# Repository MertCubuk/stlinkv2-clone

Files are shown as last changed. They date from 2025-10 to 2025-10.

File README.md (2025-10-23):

# ST-Link V2 Clone (Rev.2) — KiCad PCB Design

STM32 tabanlı bir ST-Link V2 programlayıcı kart tasarımıdır.  
Projede amaç, USB–SWD arayüzünü stabilize edecek şekilde hat eşitlemesi yapılmış,  
üretime uygun iki katmanlı bir PCB ortaya çıkarmaktır.

---

## Teknik Özellikler

- Mikrodenetleyici: STM32F103C8T6  
- Bağlantı: USB FS (12 Mbps), D+ / D− diferansiyel hat eş uzunluklu  
- Besleme: 5V → 3.3V LDO regülatör  
- Koruma: TVS diyot ile ESD koruması
- Arabirim: SWD, UART pin header (JTAG alternatifi)  
- Katman sayısı: 2  
- Minimum iz kalınlığı: 0.25 mm  
- Minimum via boyutu: 0.3 / 0.6 mm  
- PCB boyutu: Yaklaşık 70.75 × 30 mm  
- DRC: Hatasız (clearance & unconnected 0)

---

## Tasarım Notları

- D+ / D− hatları eş uzunlukta ve paralel olarak route edildi.  
- 3.3V ve 5V güç yolları kalınlaştırılarak düşük dirençli hat elde edildi.  
- Decoupling kondansatörleri MCU’ya fiziksel olarak en yakın konumda yerleştirildi.  
- Kristal çevresi kısa loop ve GND guard ile izole edildi.  
- GND plane sürekliliği korunarak düşük EMI hedeflendi.  
- Bileşenlerin silkscreen konumları okunabilirlik ve üretim kolaylığına göre düzenlendi.

---

## Görseller

### PCB Üst Katman (3D)
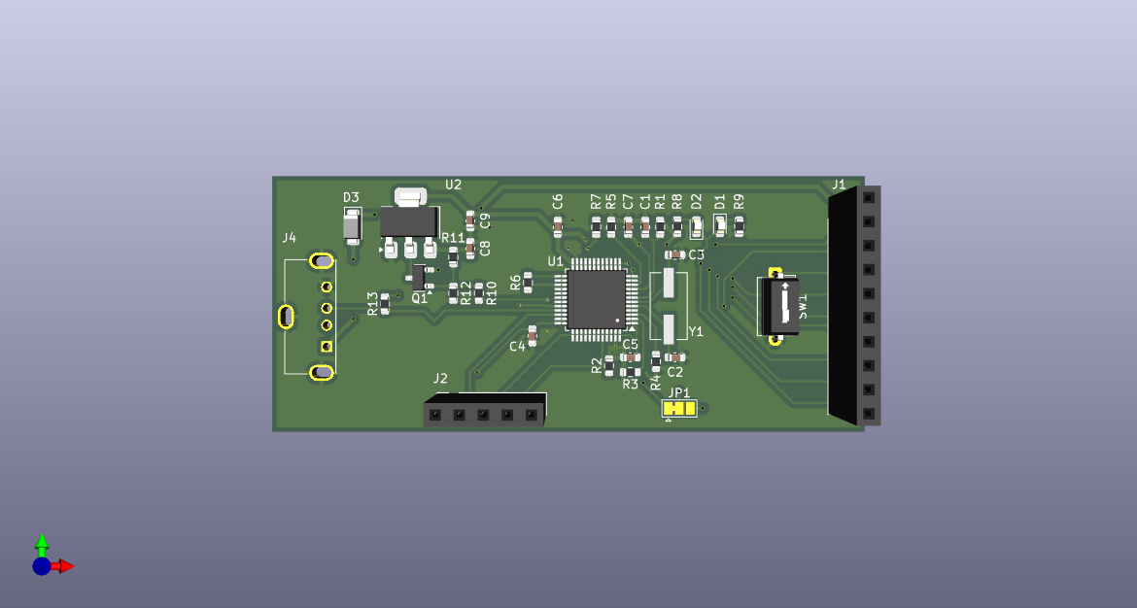
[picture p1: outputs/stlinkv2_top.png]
PCB Top


### PCB Alt Katman (3D)
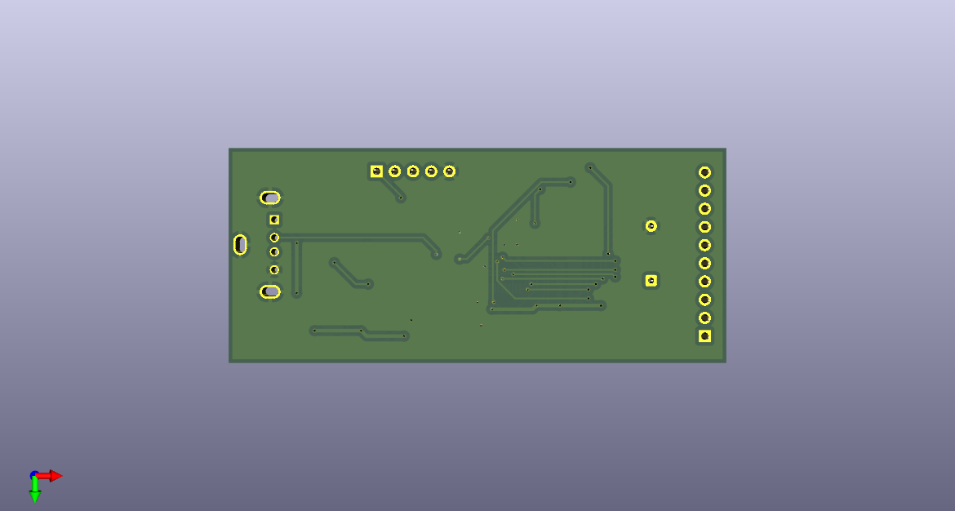
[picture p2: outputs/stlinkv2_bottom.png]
PCB Bottom


### Düzenleme Görünümü (KiCad)
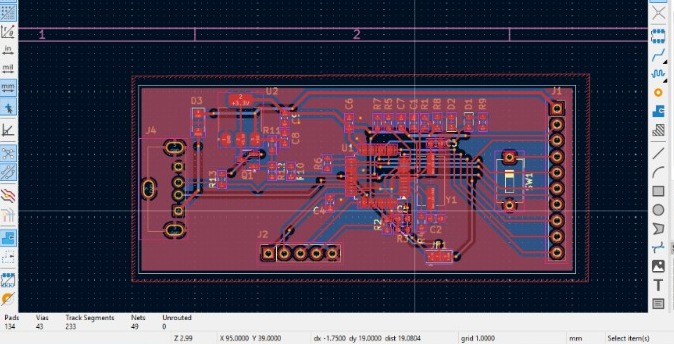
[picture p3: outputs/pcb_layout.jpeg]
PCB Layout


---

## Üretim ve Çıktılar

- Gerber + Drill dosyaları `outputs/gerbers_drill.rar` klasöründe yer alır.  
- JLCPCB / PCBWay üretim kurallarına uyumludur.  
- Şematik dosyası `.pdf` formatında eklendi (`stlinkv2_schmatic.pdf`).  
- BOM listesi ve netlist, KiCad v9+ üzerinde otomatik oluşturulabilir.

---

## Tasarım

Mert Çubuk  
Elektrik-Elektronik Mühendisi | Embedded Systems & PCB Design  
Ekim 2025  
LinkedIn: [https://www.linkedin.com/in/mert-%C3%A7ubuk-06b53536a/]

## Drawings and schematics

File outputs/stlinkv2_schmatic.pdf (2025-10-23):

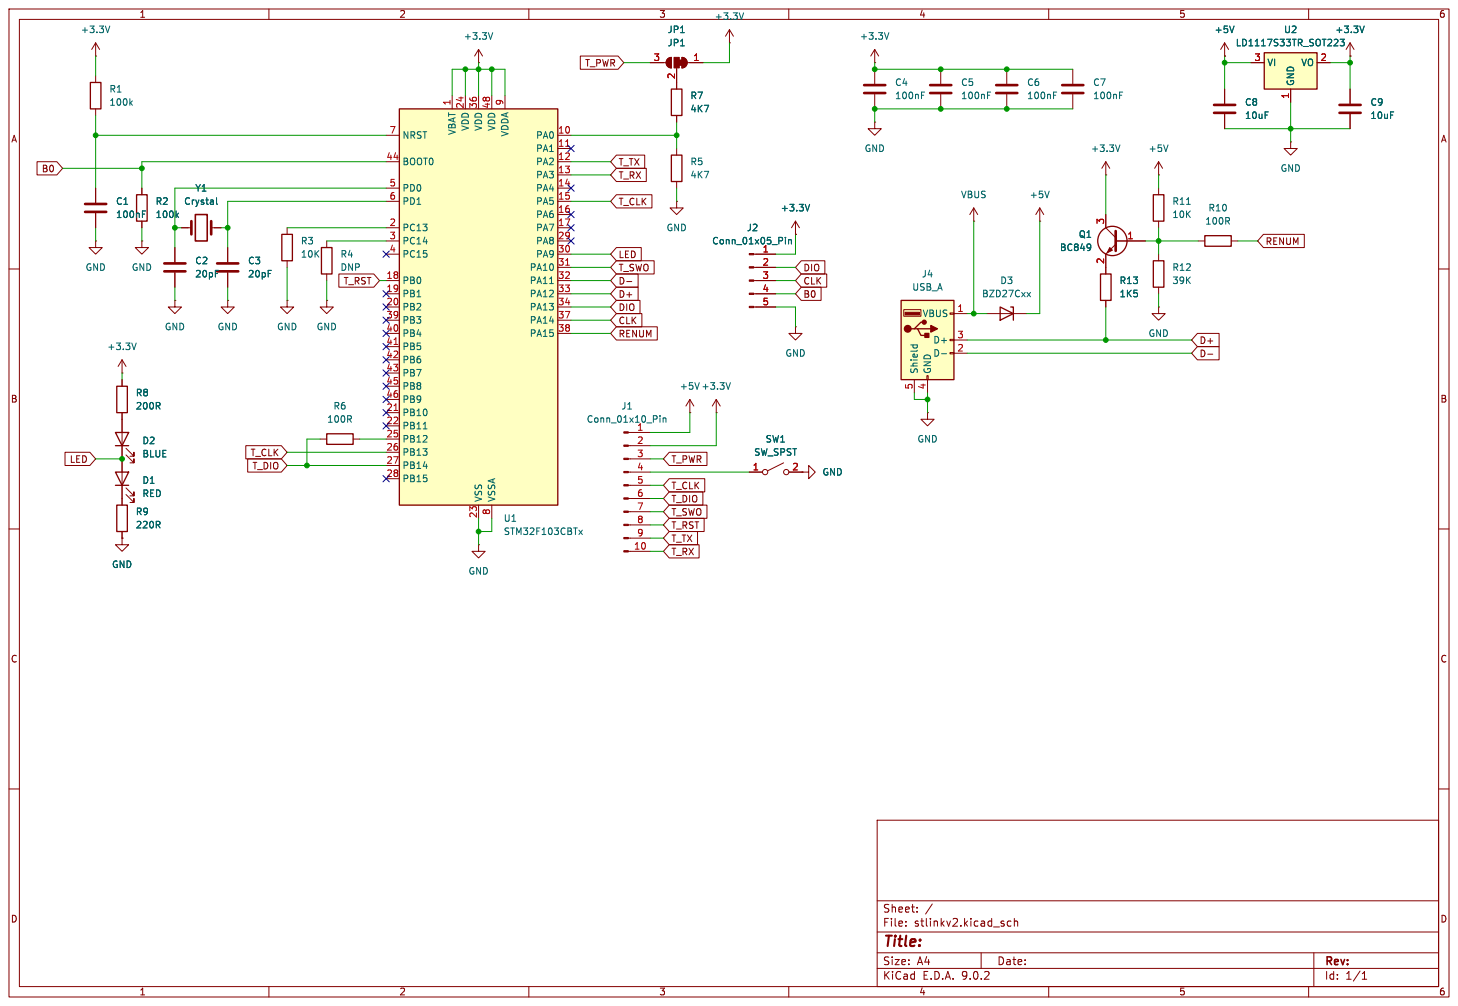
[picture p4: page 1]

1 VDD 24 VDD 36 VSS 23 VDD 48 VSSA

Id: 1/1 Title: File: stlinkv2.kicad_sch Sheet: /

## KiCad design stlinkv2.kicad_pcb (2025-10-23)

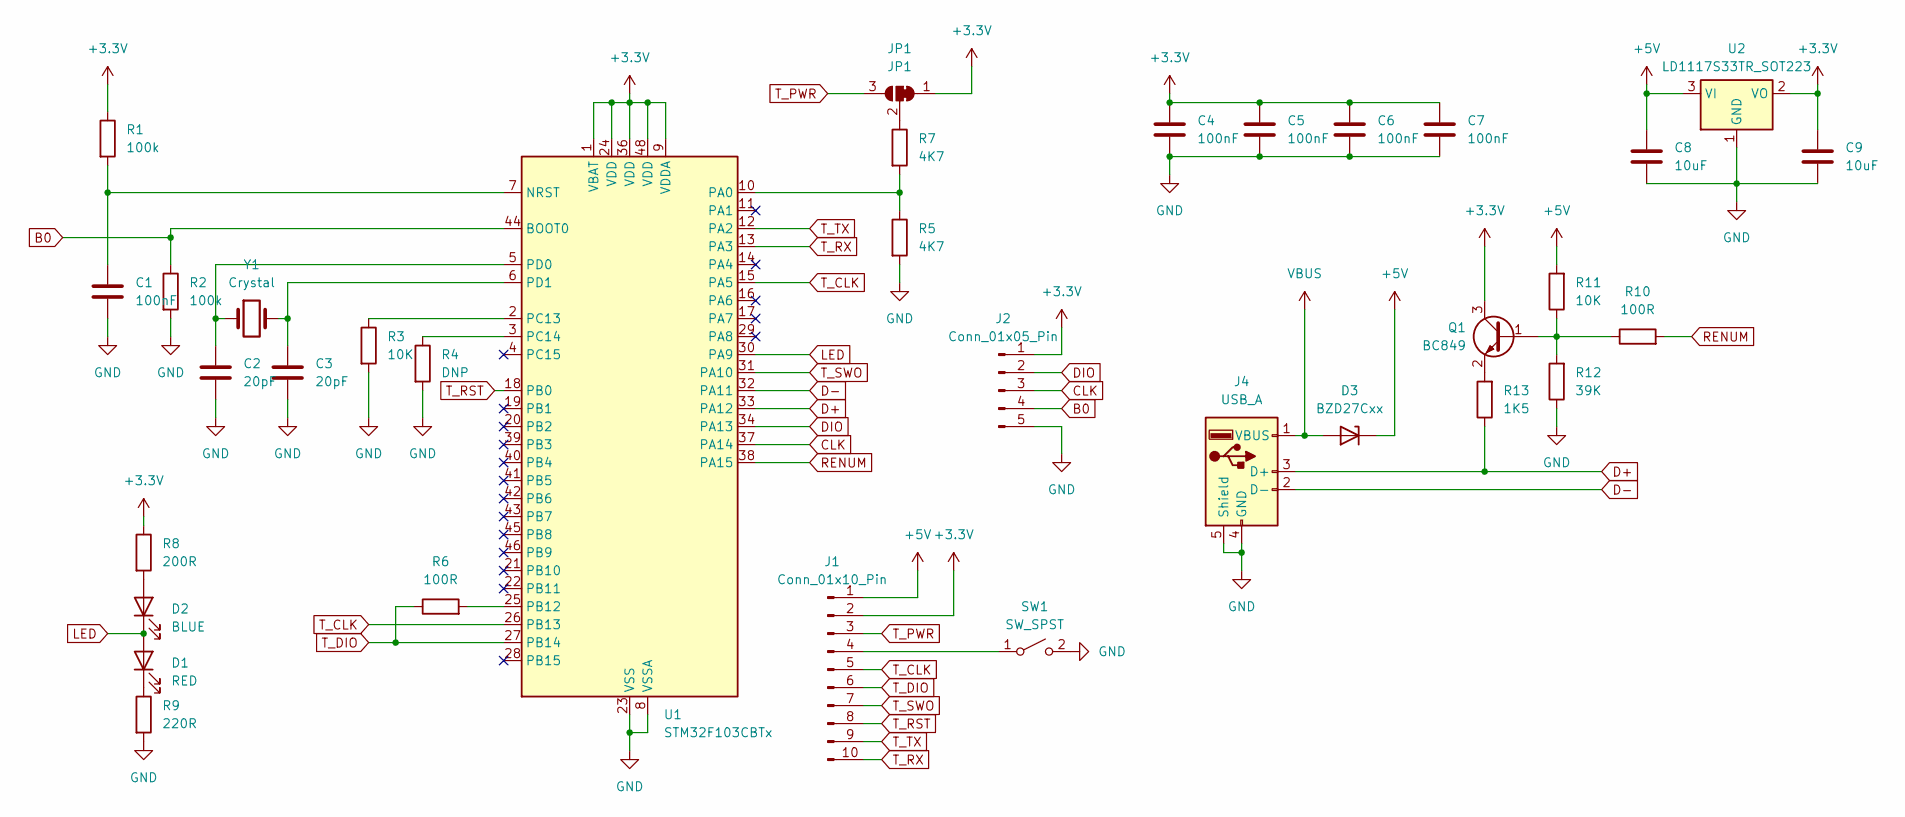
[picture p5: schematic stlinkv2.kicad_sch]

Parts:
C1, C4, C5, C6, C7: 100nF; C_0603_1608Metric
C2, C3: 20pF; C_0603_1608Metric
C8, C9: 10uF; C_0603_1608Metric
D1: RED; LED_0603_1608Metric
D2: BLUE; LED_0603_1608Metric
D3: BZD27Cxx; D_SMF
J1: Conn_01x10_Pin; PinSocket_1x10_P2.54mm_Vertical
J2: Conn_01x05_Pin; PinSocket_1x05_P2.54mm_Vertical
J4: USB_A; USB_A_Molex_105057_Vertical
JP1: JP1; SolderJumper-3_P1.3mm_Bridged12_Pad1.0x1.5mm
Q1: BC849; SOT-23
R1, R2: 100k; R_0603_1608Metric
R3, R11: 10K; R_0603_1608Metric
R4: DNP; R_0603_1608Metric
R5, R7: 4K7; R_0603_1608Metric
R6, R10: 100R; R_0603_1608Metric
R8: 200R; R_0603_1608Metric
R9: 220R; R_0603_1608Metric
R12: 39K; R_0603_1608Metric
R13: 1K5; R_0603_1608Metric
SW1: SW_SPST; SW_DIP_SPSTx01_Slide_6.7x4.1mm_W7.62mm_P2.54mm_LowProfile
U1: STM32F103CBTx; LQFP-48_7x7mm_P0.5mm
U2: LD1117S33TR_SOT223; SOT-223-3_TabPin2
Y1: Crystal; Crystal_SMD_ECS_CSM3X-2Pin_7.6x4.1mm

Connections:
+3.3V: C4.2, C5.2, C6.2, C7.2, C9.2, J1.2, J2.1, JP1.1 (A), Q1.3 (C), R1.1, R8.1, U1.1 (VBAT), U1.9 (VDDA), U1.24 (VDD), U1.36 (VDD), U1.48 (VDD), U2.2 (VO)
+5V: C8.2, D3.1 (K), J1.1, R11.2, U2.3 (VI)
B0: J2.4, R2.1, U1.44 (BOOT0)
CLK: J2.3, U1.37 (PA14)
D+: J4.3 (D+), R13.1, U1.33 (PA12)
D-: J4.2 (D-), U1.32 (PA11)
DIO: J2.2, U1.34 (PA13)
GND: C1.2, C2.2, C3.2, C4.1, C5.1, C6.1, C7.1, C8.1, C9.1, J2.5, J4.4 (GND), J4.5 (Shield), R2.2, R3.2, R4.2, R5.2, R9.2, R12.1, SW1.2 (B), U1.8 (VSSA), U1.23 (VSS), U1.35 (VSS), U1.47 (VSS), U2.1 (GND)
LED: D1.2 (A), D2.1 (K), U1.30 (PA9)
unnamed: D1.1 (K), R9.1
unnamed: D2.2 (A), R8.2
unnamed: J1.4, SW1.1 (A)
unnamed: JP1.2 (C), R7.1
unnamed: Q1.1 (B), R10.1, R11.1, R12.2
unnamed: Q1.2 (E), R13.2
unnamed: C1.1, R1.2, U1.7 (NRST)
unnamed: R5.1, R7.2, U1.10 (PA0)
unnamed: R6.2, U1.25 (PB12)
unnamed: R3.1, U1.2 (PC13)
unnamed: R4.1, U1.3 (PC14)
unnamed: C2.1, U1.5 (PD0), Y1.1
unnamed: C3.1, U1.6 (PD1), Y1.2
RENUM: R10.2, U1.38 (PA15)
T_CLK: J1.5, U1.15 (PA5), U1.26 (PB13)
T_DIO: J1.6, R6.1, U1.27 (PB14)
T_PWR: J1.3, JP1.3 (B)
T_RST: J1.8, U1.18 (PB0)
T_RX: J1.10, U1.13 (PA3)
T_SWO: J1.7, U1.31 (PA10)
T_TX: J1.9, U1.12 (PA2)
VBUS: D3.2 (A), J4.1 (VBUS)

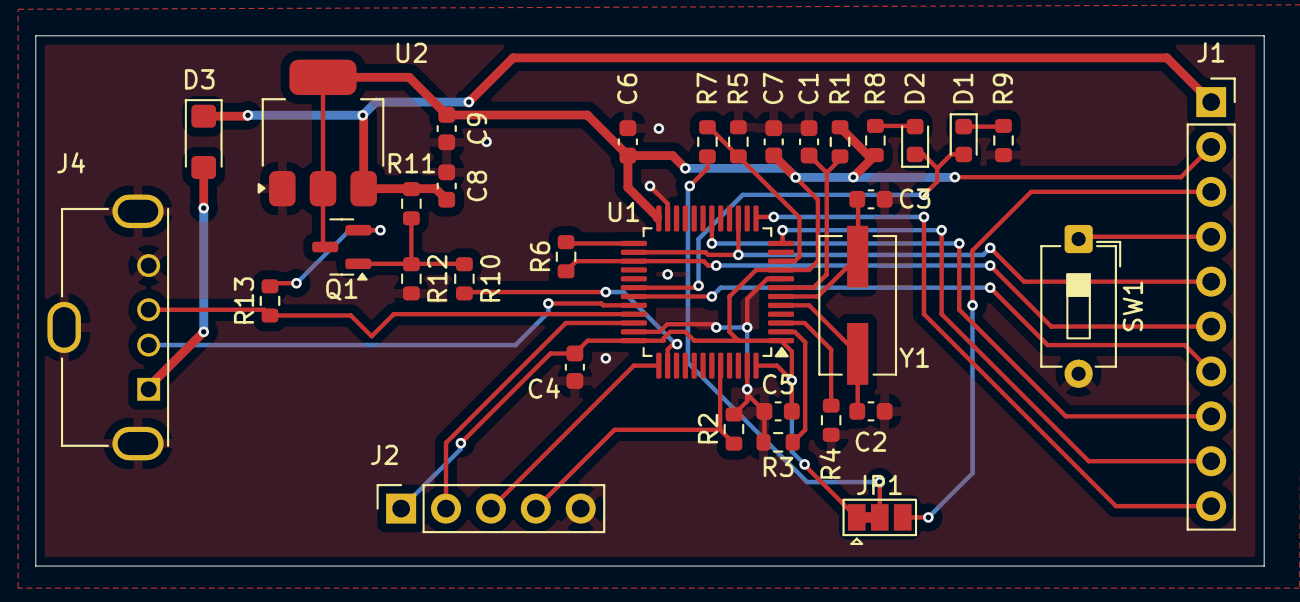
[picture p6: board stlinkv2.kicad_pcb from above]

Board: 2 copper layers, 69.5 x 30.0 mm, 34 parts (0 on the bottom side), 31 nets.
